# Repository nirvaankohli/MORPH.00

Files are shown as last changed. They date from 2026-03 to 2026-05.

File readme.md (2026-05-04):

# MORPH.00

---

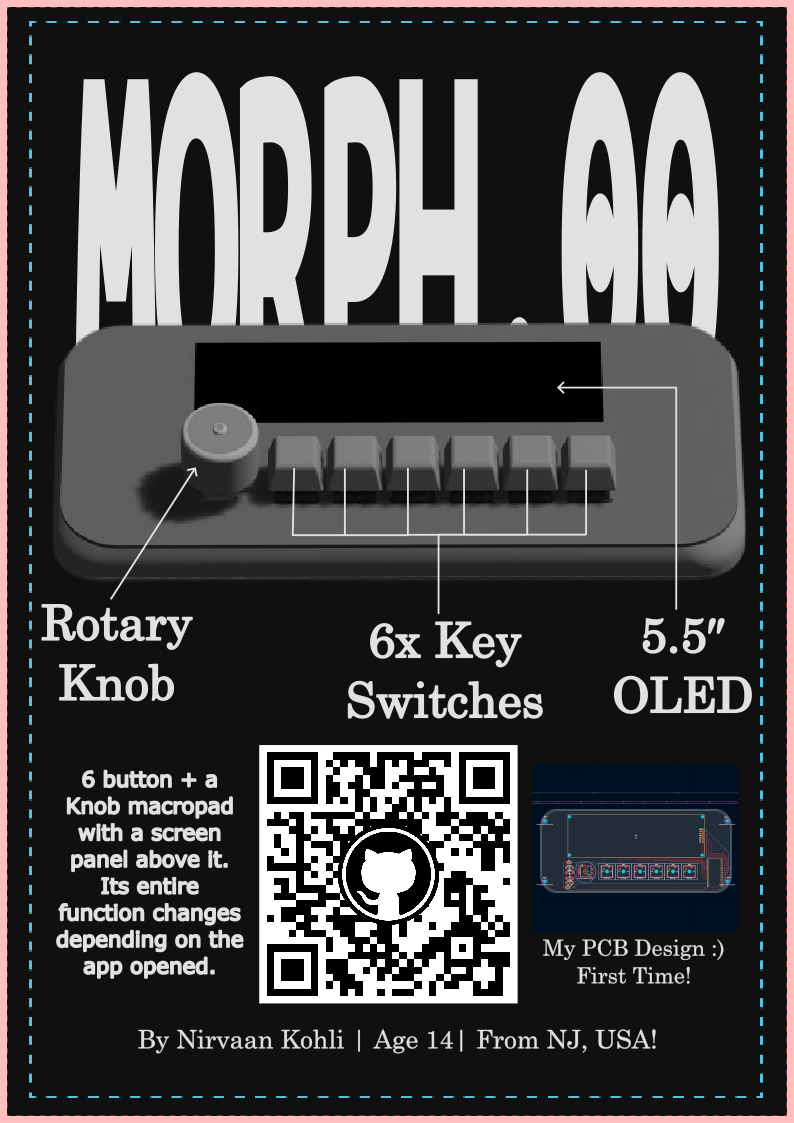
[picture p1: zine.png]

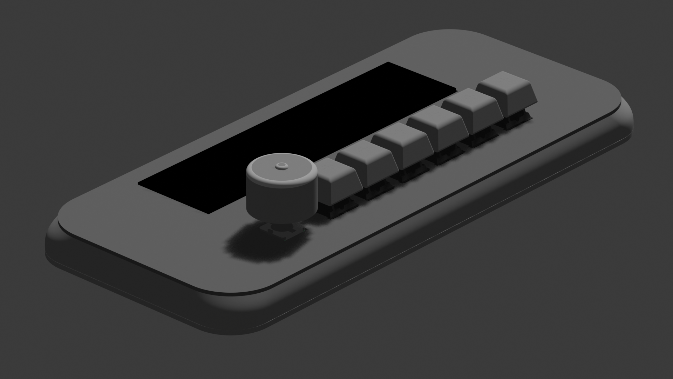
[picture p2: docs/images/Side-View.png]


MORPH.00 is a keyboard with 6 key switches and a rotary encoder that can change(morph their function). It also has an OLED to display each key or encoder's function at any given time. It is powered by the RP2040!

---

## Why choose this project?

When I initially found about fallout, I knew it was an one in a lifetime opportunity. I also knew that I did not know anything about hardware. So I looked online and on youtube and decided that a macropad was perfect for me. After a few days of brainstorming, I decided to settle for the best balance between challenging and easy(this project). Also it was pretty cool, cus like who would not want a keyboard that can change functions based on the app you are on to make work less repetitive. The use for this is legitimate because I can think of so many times in a day I press the same 6 button when in app. This would be really useful for myself, and that's why I chose to build it. Also a keyboard with a screen is rlly cool.

---

Looking back, this project was filled with a lot of firsts. I also had so much fun. Like who knew how relaxing some parts could be and how enraging others could be. Anyways, I learned my first real CAD software, onshape. I will definitely be using it in VEX Robotics as most of our team's CAD team seniored out. It took me some time to get comfortable but it is pretty cool. It was also my first time with KiCad. Making the schematic was interesting, pcb routing was so relaxing, but the errors sadly was not.

--- 

## A Little Summary

The keyboard is powered by a RP2040 on a [KB2040 Microcontroller](https://www.adafruit.com/product/5302?srsltid=AfmBOoqLa_n90N7_AYh5a78pJlOBana2qBx5fNuULukl6r5Ai2WtEuWO) running CircuitPython with many adafruit libraries. This is stuffed on the bottom-right side of the pcb board/keyboard and is the reason for it's goofy shape and proportions.

The six switches are Cherry MXs, the rotary encoder an EC11 Rotary Encoder, and the OLED a 5.5 Inch 256x64 display. There is also a part of this project on the host computer that sends info like key, encoder, or OLED changes to the keyboard.

--- 

# CAD Renderings

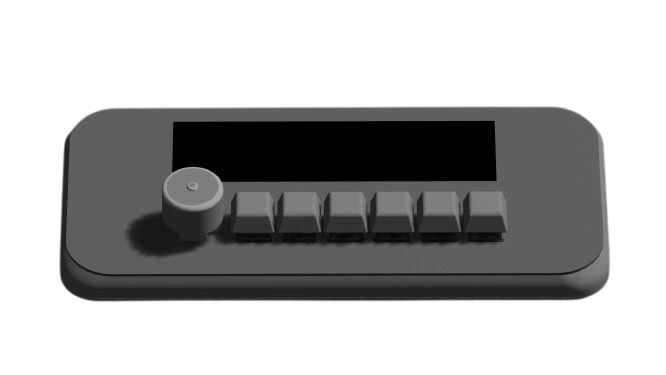
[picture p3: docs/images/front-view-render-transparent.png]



CAD was a very infuriating experience if I may add.

---

## PCB + Schematic

This is my final schematic

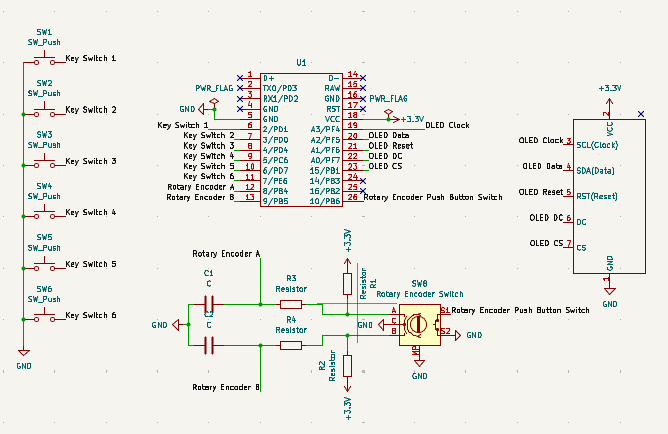
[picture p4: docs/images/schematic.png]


This schematic went through multiple, multiple changes. Like when I had to add power symbols, make a denouncer circuit, custom design the OLED symbol like 2 times, and change the GPIO pins for my OLED. I liked this portion a lot actually.

### Final PCB

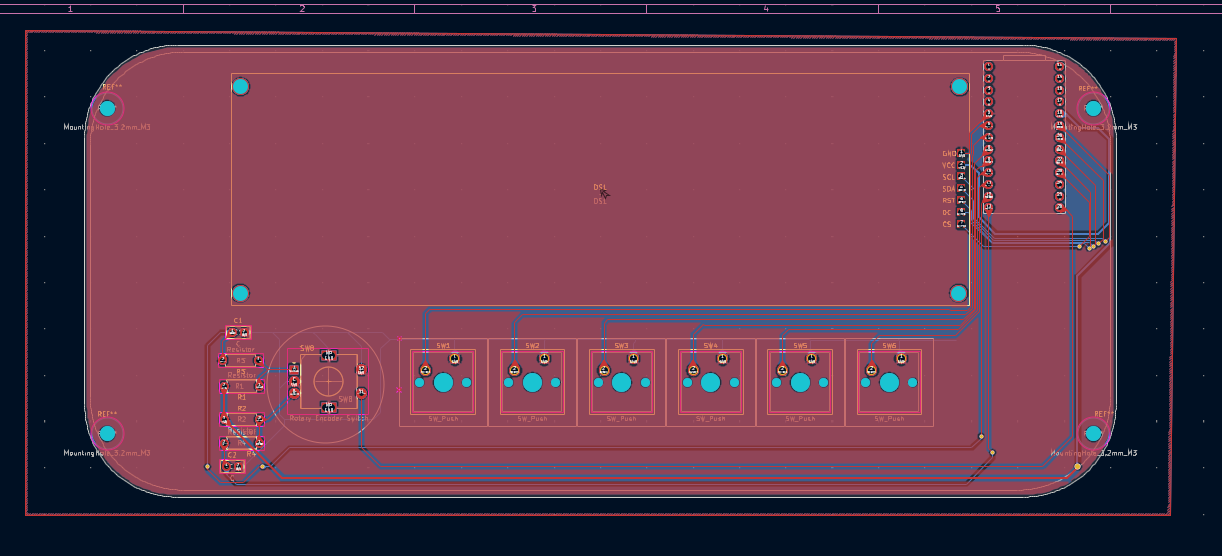
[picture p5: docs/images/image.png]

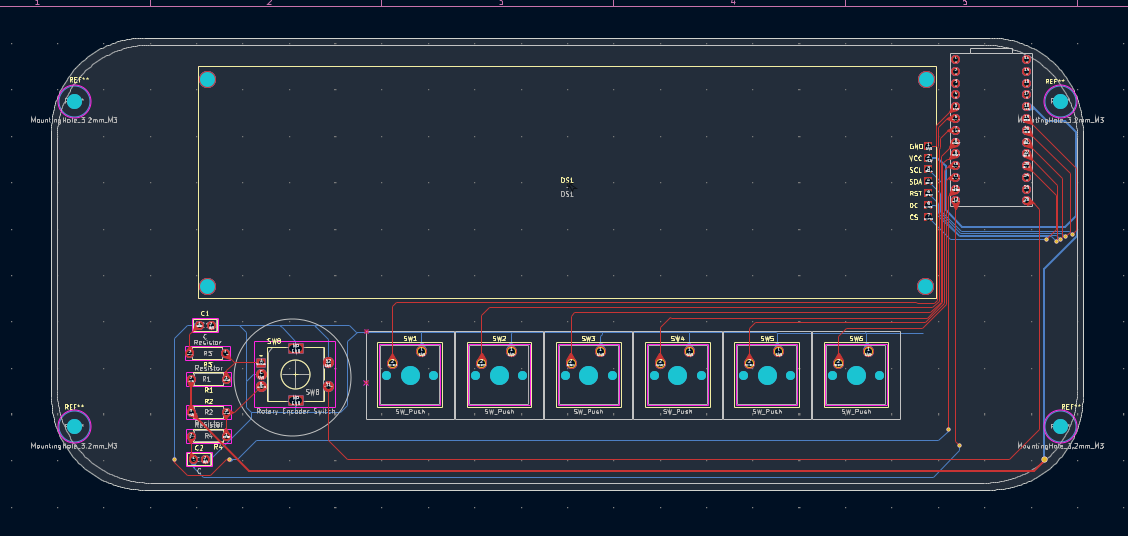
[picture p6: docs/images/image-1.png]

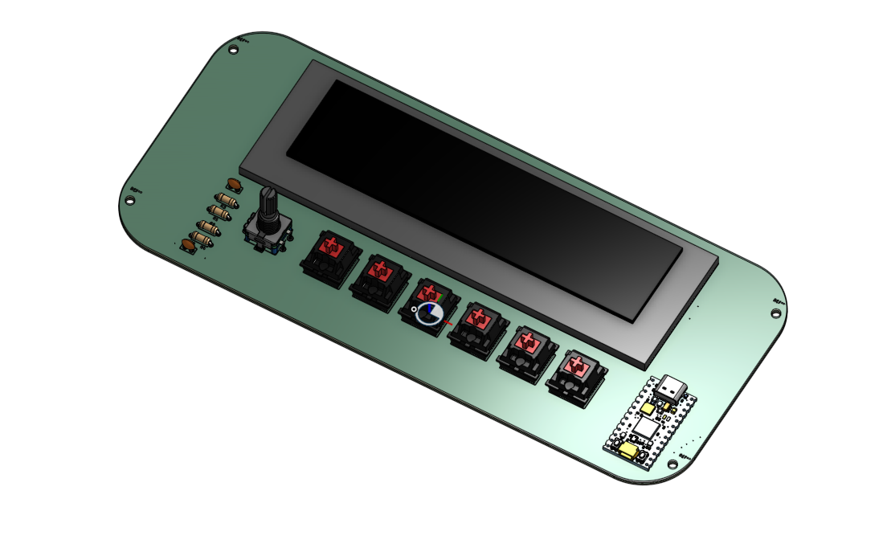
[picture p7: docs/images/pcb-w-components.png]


I added a lot of stuff bc the Internet said so :). So hopefully that was not a mistake. I was also just informed no 90 or acute angles so maybe not so final pcb :(.

----

### How to Use It?

This is relatively easy to use assuming it is all put together and well. All you need to do is drag firmware/software files into the KB2040 and let the host computer code run as a background process.

The computer process will be listening on a port. From there you can read the documentation available in code/keyboard/ on how to automate the OLED, switches, and encoder functions. 

From there, it is just using the macropad as a macropad.

---

# How to construct it?

Since I have not had the pleasure of constructing this, I can't tell you for sure but below is how to build it if everything goes as planned.

1. Soldering Components
   1. This step assumes you have bought everything in the BOM.
   2. The first step is to solder all the components on to the PCB.
      1. Use the various KiCad files as reference to know where to put components if you are confused.
2. 3D Printing Case
   1. This again assumes you have a 3D printer or some way to get your hands on a physical version of the case(files in /cad).
   2. This is pretty self-explanatory as you need to obtain all 3D printed objects in cad/print.
3. Assembling the Body of the Macropad
   1. Use M3 screws and nylocks to fasten the OLED on to the PCB plate.
   2. Put the top plate on the board.
   3. It should click into place thanks to the Cherry MX switches.
   4. Slide your usb c cable through the hole on the side of the case. For future use plug that cable into your host computer.
   5. Then take your 3mm Spacer and insert it between the bottom of the PCB and plate
   6. Insert the screw on the bottom of the bottom plate 
   7. On the top of the pcb plate place a M3 nylock and fasten.
   8. Repeat for all other 3 corners.
   9. For extra precaution optionally add some type of adhesive between the top plate's side and the bottom plate's edges.
4. Add Keycaps and Cover for Encoder
   1. Start by putting a keycap on one of the switches. The keycap should slide in and click.
   2. Repeat for the remaining 5 keycaps.
   3. For the Rotary Encoder, simply press down the rotary encoder cover on the Rotary Encoder, and with some force it should slide in.

---

Congrats! You have know constructed MORPH.00. Hopefully it should work.

---

# BOM

Check `bom.csv`!

---

# Onshape Link

[Onshape](https://cad.onshape.com/documents/fb2e845d06a2abfe6a4c7c6e/w/d1b8caaf10144fcbff733afe/e/741c88277487ad0443e0a772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)

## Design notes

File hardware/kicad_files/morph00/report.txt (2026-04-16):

Update symbol #FLG01 from 'power:PWR_FLAG' to 'power:PWR_FLAG': OK
Update symbol #PWR07 from 'power:+3.3V' to 'power:+3.3V': OK
Update symbol #FLG02 from 'power:PWR_FLAG' to 'power:PWR_FLAG': OK
Update symbol #PWR011 from 'power:GND' to 'power:GND': OK
Update symbol #PWR05 from 'power:+3.3V' to 'power:+3.3V': OK
Update symbol #PWR013 from 'power:GND' to 'power:GND': OK
Update symbol #PWR06 from 'power:+3.3V' to 'power:+3.3V': OK
Update symbol SW5 from 'Switch:SW_Push' to 'Switch:SW_Push': OK
Update symbol SW1 from 'Switch:SW_Push' to 'Switch:SW_Push': OK
Update symbol SW4 from 'Switch:SW_Push' to 'Switch:SW_Push': OK
Update symbol R3 from 'ScottoKeebs:Placeholder_Resistor' to 'ScottoKeebs:Placeholder_Resistor': OK
Update symbol R4 from 'ScottoKeebs:Placeholder_Resistor' to 'ScottoKeebs:Placeholder_Resistor': OK
Update symbol SW3 from 'Switch:SW_Push' to 'Switch:SW_Push': OK
Update symbol #PWR09 from 'power:GND' to 'power:GND': OK
Update symbol #PWR08 from 'power:GND' to 'power:GND': OK
Update symbol #PWR010 from 'power:+3.3V' to 'power:+3.3V': OK
Update symbol #PWR01 from 'power:GND' to 'power:GND': OK
Update symbol C1 from 'Device:C' to 'Device:C': OK
Update symbol C2 from 'Device:C' to 'Device:C': OK
Update symbol DS1 from 'OLED:TZT_5.5_OLED_SSD1322' to 'OLED:TZT_5.5_OLED_SSD1322': OK
Update symbol #PWR04 from 'power:GND' to 'power:GND': OK
Update symbol SW7 from 'Device:RotaryEncoder_Switch' to 'Device:RotaryEncoder_Switch': OK
Update symbol U1 from 'ScottoKeebs:MCU_Adafruit_KB2040' to 'ScottoKeebs:MCU_Adafruit_KB2040': OK
Update symbol #PWR02 from 'power:GND' to 'power:GND': OK
Update symbol SW6 from 'Switch:SW_Push' to 'Switch:SW_Push': OK
Update symbol #PWR03 from 'power:GND' to 'power:GND': OK
Update symbol SW2 from 'Switch:SW_Push' to 'Switch:SW_Push': OK
Update symbol R1 from 'ScottoKeebs:Placeholder_Resistor' to 'ScottoKeebs:Placeholder_Resistor': OK
Update symbol R2 from 'ScottoKeebs:Placeholder_Resistor' to 'ScottoKeebs:Placeholder_Resistor': OK
Update symbol #PWR012 from 'power:GND' to 'power:GND': OK

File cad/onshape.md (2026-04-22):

[Onshape Link](https://cad.onshape.com/documents/fb2e845d06a2abfe6a4c7c6e/w/d1b8caaf10144fcbff733afe/e/741c88277487ad0443e0a772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)

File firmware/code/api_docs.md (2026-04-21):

# API Docs

## Setup

To start, make sure you have the latest version of pip & python.

Then go into in an editor and edit `app.py`'s `OS` to your OS(windows, linux, or mac).

Depending on your os change either `LINUX_AND_MAC_PORT`(linux or mac) or `COM_NUM`(windows) to what port your macropad is connected to.

Once you have made sure of that run the following commands:

```bash

cd morph.00/code/computer
pip install -r requirements.txt
python app.py

```

The app should be up and running. You should get text in your terminal like(will change a little bit depending on your device):

```
 * Serving Flask app 'app'
 * Debug mode: on
WARNING: This is a development server. Do not use it in a production deployment. Use a production WSGI server instead.
 * Running on http://127.0.0.1:5000
Press CTRL+C to quit
 * Restarting with watchdog (windowsapi)
 * Debugger is active!
 * Debugger PIN: 116-642-025

```

To ensure the app is working get the first endpoint:

```text
GET /
```

or just run this:

`curl http://127.0.0.1:5000/`

If all is well you should get something like:

`{"message": "MORPH serial bridge is running."}`

## Keys

Below are the endpoints to change key functions.

```text
POST /messages/send
POST /messages/send/<key_num>
POST /messages/send/<key_num>/<executable_type>
```

* `POST /messages/send`
  * The payload needs to contain:
    * `type: "key_func_change"` - needs to be set to this if you want to change a key_function - can also be not be there and the app will handle the rest
    * `key_num` - The key number you want to change. Goes from 0 to 5 - order is left to right as the key number increases.
    * `executable_type` - what you want the key's function be
      * `string` - types a string
      * `key` - presses key
      * `key_combo` - presses key_combo
      * `consumer_control` - look at `adafruit_hid.consumer_control` dpcs for more info
    *  `executable`
       *   The executable itself - refer to each type's code to figure out what this should be
   * Other optional functions are available
* `POST /messages/send/<key_num>`
  * Same thing as `POST /messages/send` but `key_num` is specified in request url instead of in the payload
* `POST /messages/send/<key_num>/<executable_type>`
  * Same thing as `POST /messages/send` but `key_num` and `executable_type` is specified in request url instead of in the payload

## Rotary Encoder

```text
POST /encoder/send
POST /encoder/send/<encoder_action>
```

* `POST /encoder/send` 
  * The payload needs to contain:
    * `type: encoder_func_change`- needs to be set to this if you want to change a encoder_function - can also be not be there and the app will handle the rest
    * `encoder_action` 
      * `clockwise`- if clockwise movement affects the value
      * `counterclockwise` - if counterclockwise movement affects the value
      * `button` - use it as a button
    * `executable_type`
      * `string` - types a string
      * `key` - presses key
      * `key_combo` - presses key_combo
      * `consumer_control` - look at `adafruit_hid.consumer_control` dpcs for more info
    * `executable`
      * The executable itself - refer to each type's code to figure out what this should
* `POST /encoder/send/<encoder_action>` 
  * Same thing as `POST /encoder/send` but the `encoder_action` is specified in the request url
## OLED

```text
POST /oled/send
POST /oled/send/default
```

* `POST /oled/send` 
  * The payload needs to contain:
    * `type: display_change`- needs to be set to this if you want to change the display - can also be not be there and the app will handle the rest
    * `pixels` - the pixels you want to set the OLED to
* `POST /oled/send/default`
  * Same thing idk why I created a whole new endpoint

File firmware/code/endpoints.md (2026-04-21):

# API Endpoints

## General

```text
GET /
```

## Keys

```text
POST /messages/send
POST /messages/send/<key_num>
POST /messages/send/<key_num>/<executable_type>
```

## Rotary Encoder

```text
POST /encoder/send
POST /encoder/send/<encoder_action>
```

## OLED

```text
POST /oled/send
POST /oled/send/default
```

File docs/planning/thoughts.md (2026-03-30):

## Components to Use

- Microcontroller
  - Criterion
    - Have enough power to receive data from computer, process it and then display images on OLED
    - Be easy enough to use and be small enough for my form factor
  - Options
    - Raspberry Pi RP2040
      - Pros
        - Faster
        - More Memory
        - Used by most people
      - Cons
        - Still simple, just less than the ATmega32U4
    - ATmega32U4 (Arduino Pro Micro)
      - Pros
        - Simple
      - Cons
        - Performance
- Switches
  - Criterion
    - Durability
    - Consistency
    - Feel
  - Cherry MX Red
    - Both RED & BLack are equal and very good in durability and consistency
    - Light
    - Quiet
    - Smooth
  - Cherry MX Black
    - Both RED & BLack are equal and very good in durability and consistency
    - Smooth 
    - Heavy
    - When lubricated - buttery(big priority)

- Rotary Encoder
  - Criterion
    - Durable
    - Smooth
    - Consistent
  - Some I found online
    - Everything pointed to EC-11 type encoders - a bit about them
      - They are budget-friendly
      - 360 degree endless rotations
      - Compact Size

What I chose

- RP2040 - KB2040
- Cherry MX Black
- EC11 Rotary Encoder
- OLED: https://www.aliexpress.us/item/3256808352565291.html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 - 5.5 INCH 256 x 64

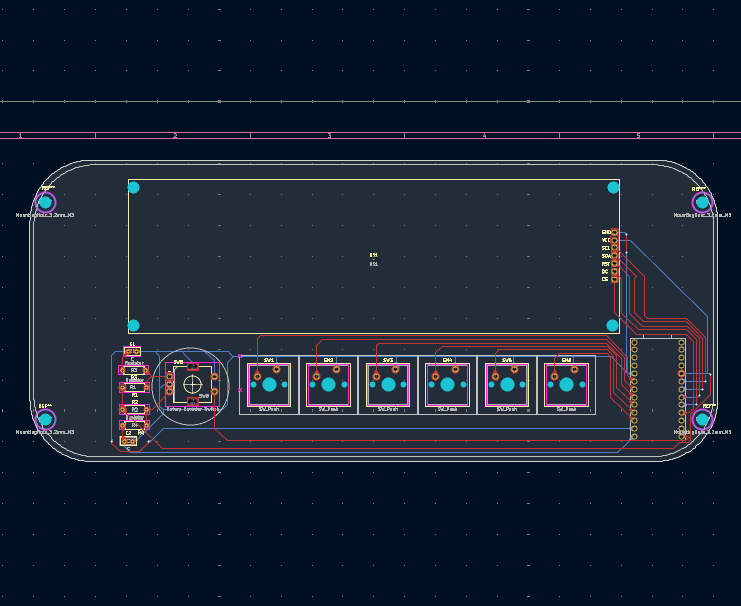
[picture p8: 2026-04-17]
hardware/kicad_files/morph00/Screenshot 2026-04-16 180610.png

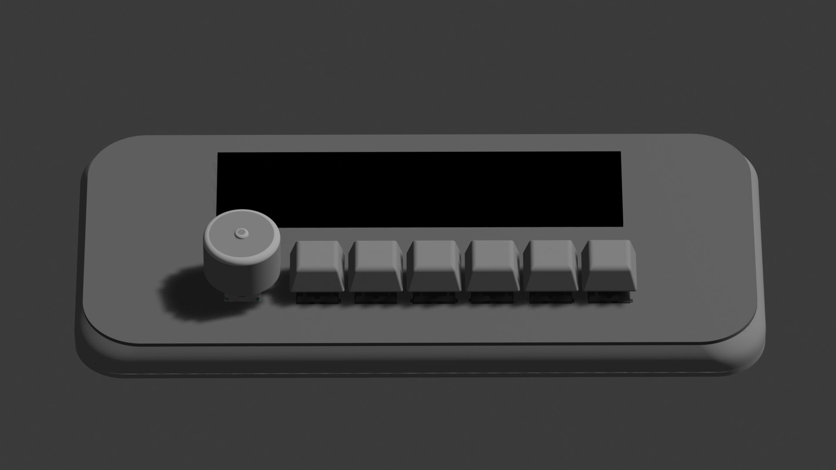
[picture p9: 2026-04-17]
hardware/kicad_files/morph00/Morph0.png

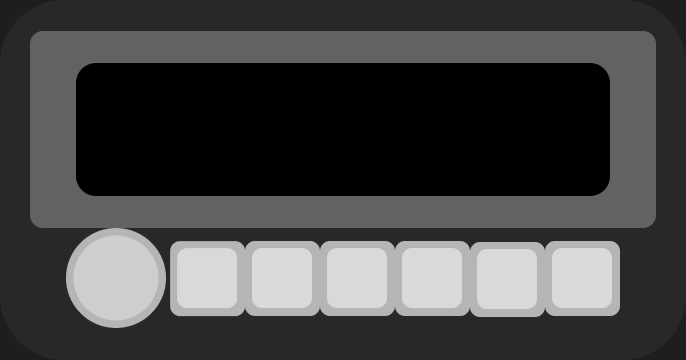
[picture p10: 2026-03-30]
docs/planning/figma/MORPH00.png

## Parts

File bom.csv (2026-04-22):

Part Name | Description | Quantity | Unit | Price Used | Total Price | Link
KB2040 | Microcontroller | 1 | piece | $8.95 | $8.95 | https://www.digikey.com/en/products/detail/adafruit-industries-llc/5302/15794634
5.5 Inch OLED LCD Display Green / Yellow Color TZT 256x64 Drive SSD1322 Interface SPI/ 8-bit Parallel Port For Arduino UNO R3 | OLED Display | 1 | piece | $35.83 | $35.83 | https://www.aliexpress.us/item/3256808352565291.html?curPageLogUid=hwy6wPt4U5Ww
360 Degree Rotary Encoder EC11 With Push Button 5Pin 20 Positions 20 Pulse Code Switch Handle 15/20MM Digital Potentiometer | G 20mm Plum handle Rotary Encoder | 1 | piece | $0.99 | $0.99 | https://www.aliexpress.us/item/3256807457768762.html?src=google&gatewayAdapt=glo2usa
Cherry MX HP 5 Pins Black Switch Hyperglide 60g Linear Custom Hot Swap MX Switches Mechanical Keyboard Gaming Switch Lubricatde | Cherry MX Black | 1 | 10 piece | $7.75 | $7.75 | https://www.aliexpress.us/item/3256808625020299.html?curPageLogUid=G7crrMlf338z
100pcs 50V monolithic ceramic capacitor 10PF ~ 10UF 22PF 47NF 220NF 1NF 4.7UF 1UF 100NF 330NF 0.1UF 102 104 105 106 103 473 334 | Capacitor(100 NF) | 4 | pieces | $2.04 | $2.04 | https://www.aliexpress.us/item/2251832786944590.html
100PCS/LOT 1/4W 1% Metal Film Resistor 0.25W 0.1 0.15 1.5 12 33 47 68 100 150 240 560 1K 3.3K 8.2K 10K 100K 680K 1M 10M 22M ohms | Resistors 10kΩ | 2 | pieces | $0.0099 | $0.99 | https://www.aliexpress.us/item/3256801441680644.html
USB C Cable | USB C Cable | 1 | pieces | $5.99 | $5.99 | https://a.co/d/0d05Bpac
M3 x 12mm Screws | M3 x 12mm Screws | 4 | pieces | $0.48 | $5.99 | https://a.co/d/0d2OkMbH
M3 4mm Spacers(Nylon) |  | 4 | pieces | $0.22 | $5.41 | https://a.co/d/0bYEqd7h
Filament | Just Filament | 107.35 | grams | $1.50 | $13.99 | https://a.co/d/03jPNyWm
Super Glue | Optional | Depends | Depends | $2.12 | $2.12 | https://a.co/d/06pQ8V2r

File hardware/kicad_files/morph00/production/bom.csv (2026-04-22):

Designator | Footprint | Quantity | Value | LCSC Part #
C1, C2 | C_Disc_D5.0mm_W2.5mm_P2.50mm | 2 | C
DS1 | TZT_5.5_OLED_SSD1322 | 1 | ~
R1, R2, R3, R4 | R_Axial_DIN0207_L6.3mm_D2.5mm_P7.62mm_Horizontal | 4 | Resistor
SW1, SW2, SW3, SW4, SW5, SW6 | SW_Cherry_MX_1.00u_PCB | 6 | SW_Push
SW8 | RotaryEncoder_Alps_EC11E-Switch_Vertical_H20mm | 1 | Rotary Encoder Switch
U1 | Adafruit_KB2040 | 1 | ~

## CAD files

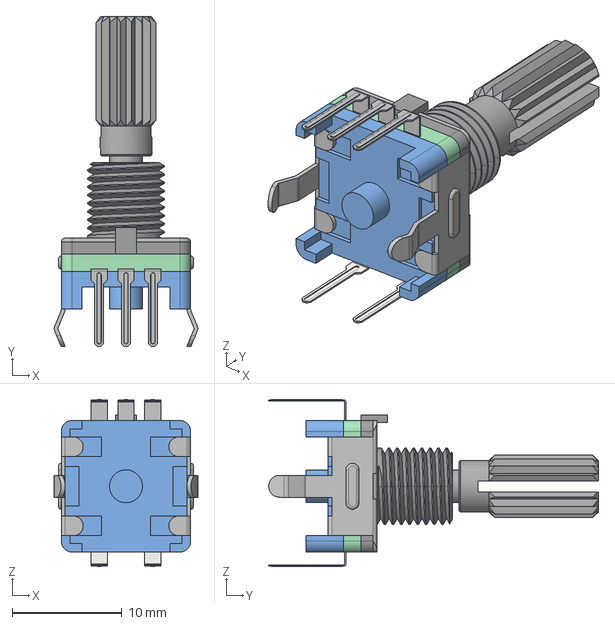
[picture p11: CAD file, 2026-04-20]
cad/components/EC11 Alps Rotary Encoder.step
13.1 x 30.1 x 15.3 mm

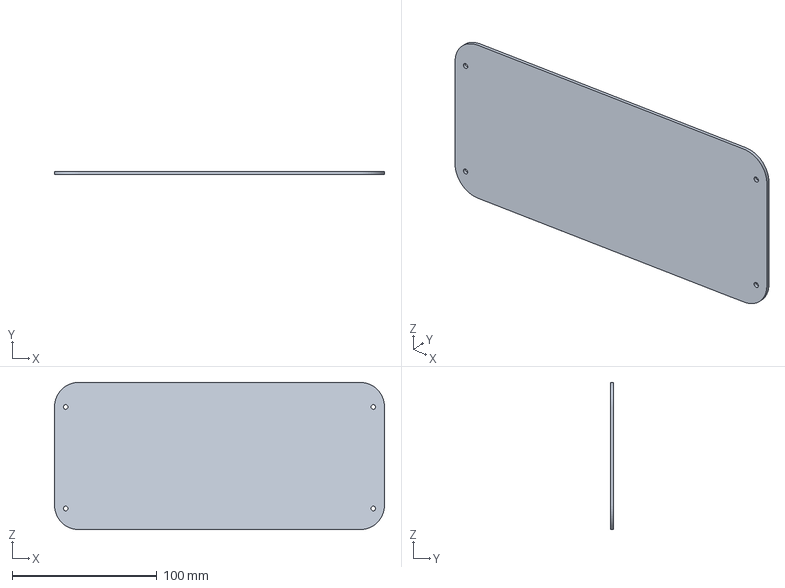
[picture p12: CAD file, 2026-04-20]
cad/print/Bottom Plate/Bottom Plate.step
228.3 x 2.00 x 101.9 mm

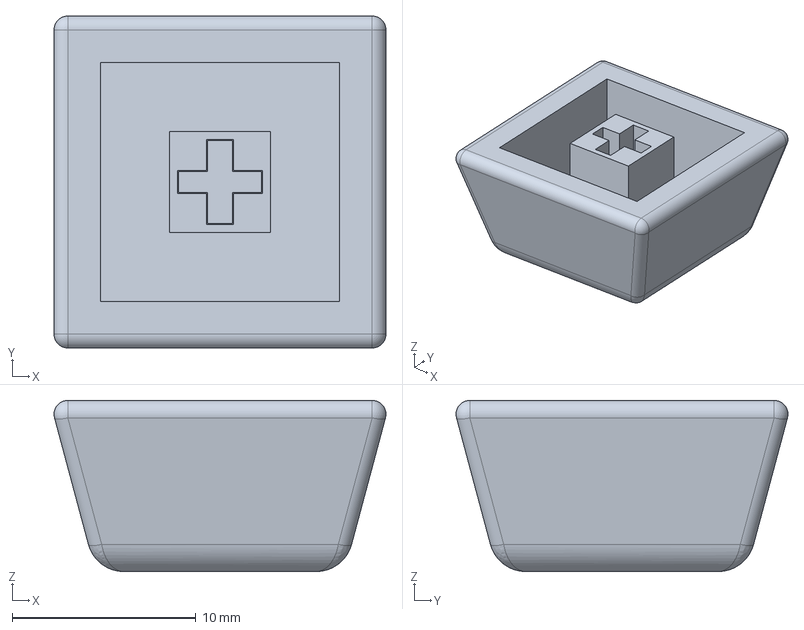
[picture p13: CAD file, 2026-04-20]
cad/print/Key Cap/Key Cap.step
18.0 x 18.0 x 9.30 mm

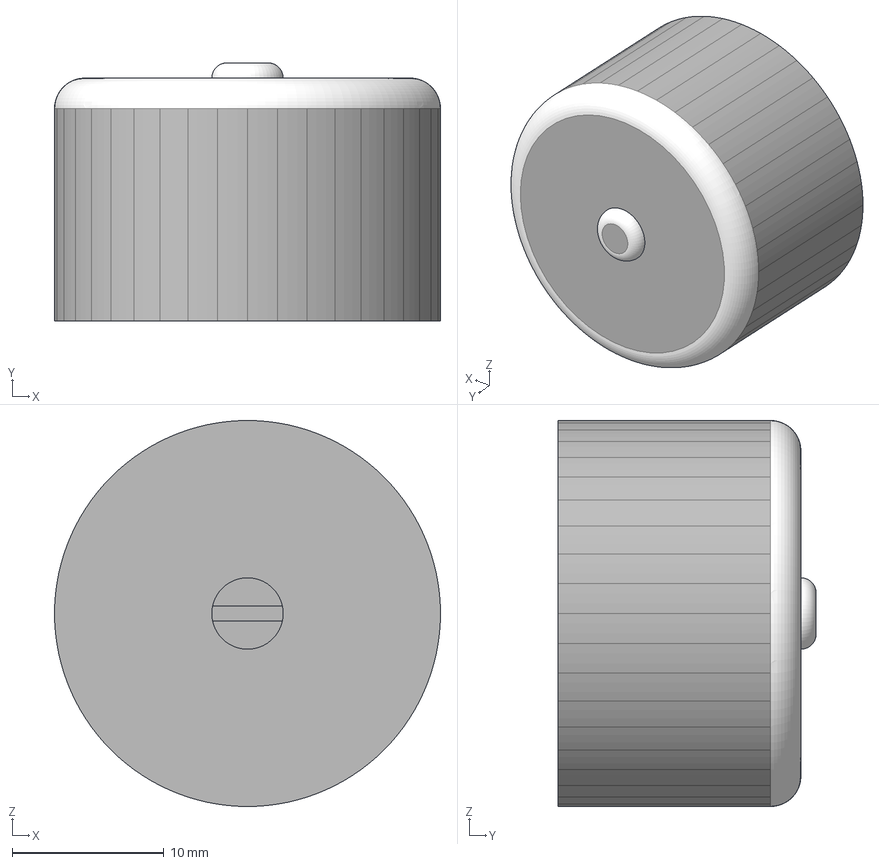
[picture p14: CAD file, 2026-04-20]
cad/print/Rotary Encoder Knob 3D Model/Rotary Encoder Knob 3D Model.step
25.4 x 17.0 x 25.4 mm

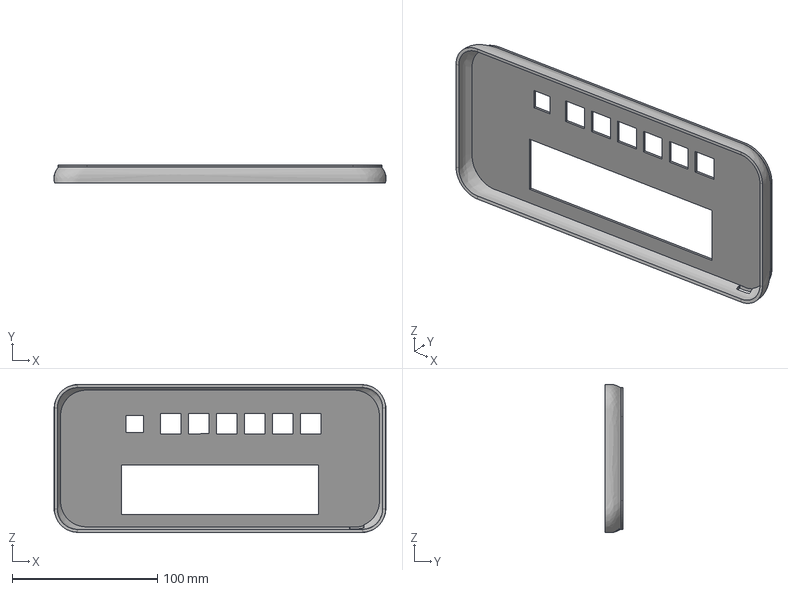
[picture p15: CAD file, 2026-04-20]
cad/print/Top Plate/Top Plate.step
228.3 x 12.5 x 101.9 mm

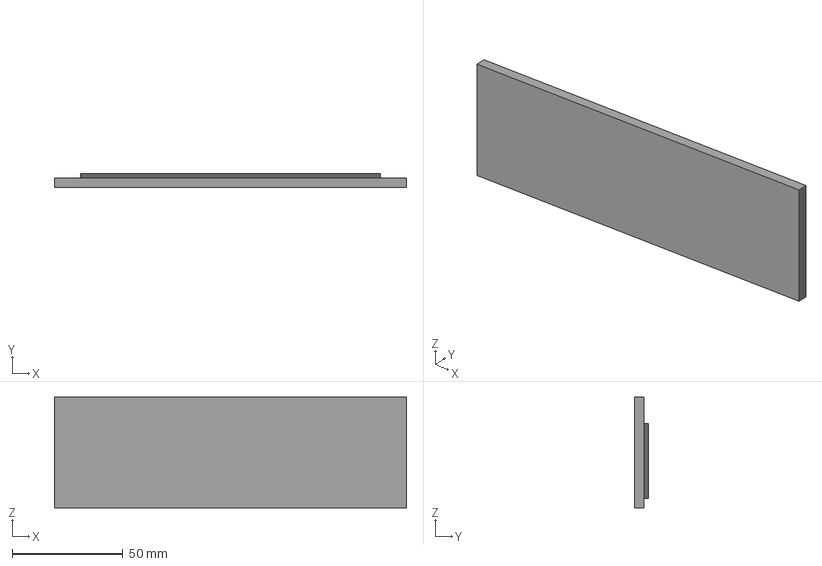
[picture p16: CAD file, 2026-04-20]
cad/components/OLED Screen Part Studio.step
159.0 x 6.40 x 50.0 mm

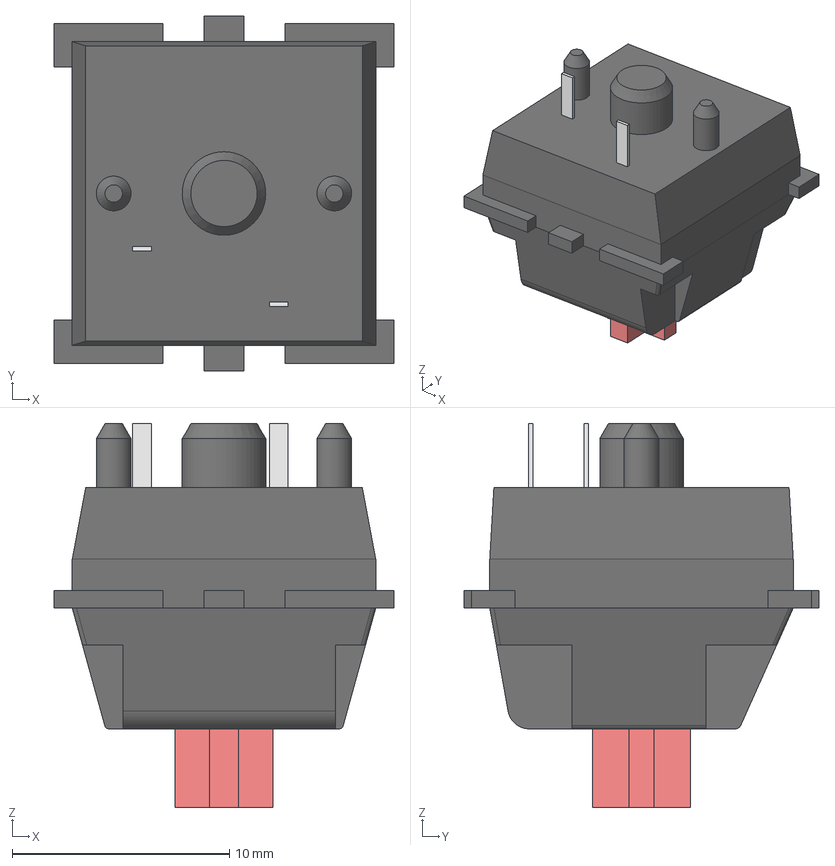
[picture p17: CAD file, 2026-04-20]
cad/components/Cherry MX Switch(Red).step
15.6 x 16.3 x 17.7 mm

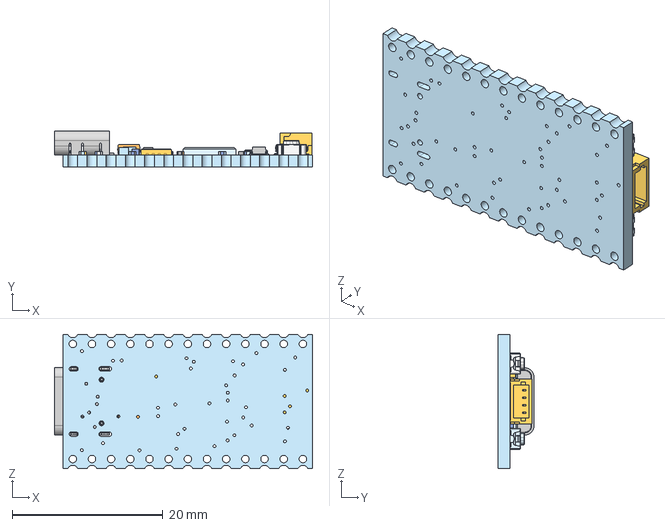
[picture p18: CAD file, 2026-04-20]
cad/components/Adafruit KB2040.step
34.2 x 4.77 x 17.8 mm
pcb 1.1.1 x 87

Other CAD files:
cad/print/Bottom Plate/Bottom Plate.obj
cad/print/Bottom Plate/Bottom Plate.stl
cad/print/Key Cap/Key Cap.obj
cad/print/Key Cap/Key Cap.stl
cad/print/Rotary Encoder Knob 3D Model/Rotary Encoder Knob 3D Model.obj
cad/print/Rotary Encoder Knob 3D Model/Rotary Encoder Knob 3D Model.stl
cad/print/Top Plate/Top Plate.obj
cad/print/Top Plate/Top Plate.stl

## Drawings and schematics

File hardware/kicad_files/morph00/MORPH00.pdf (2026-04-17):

# MORPH.00

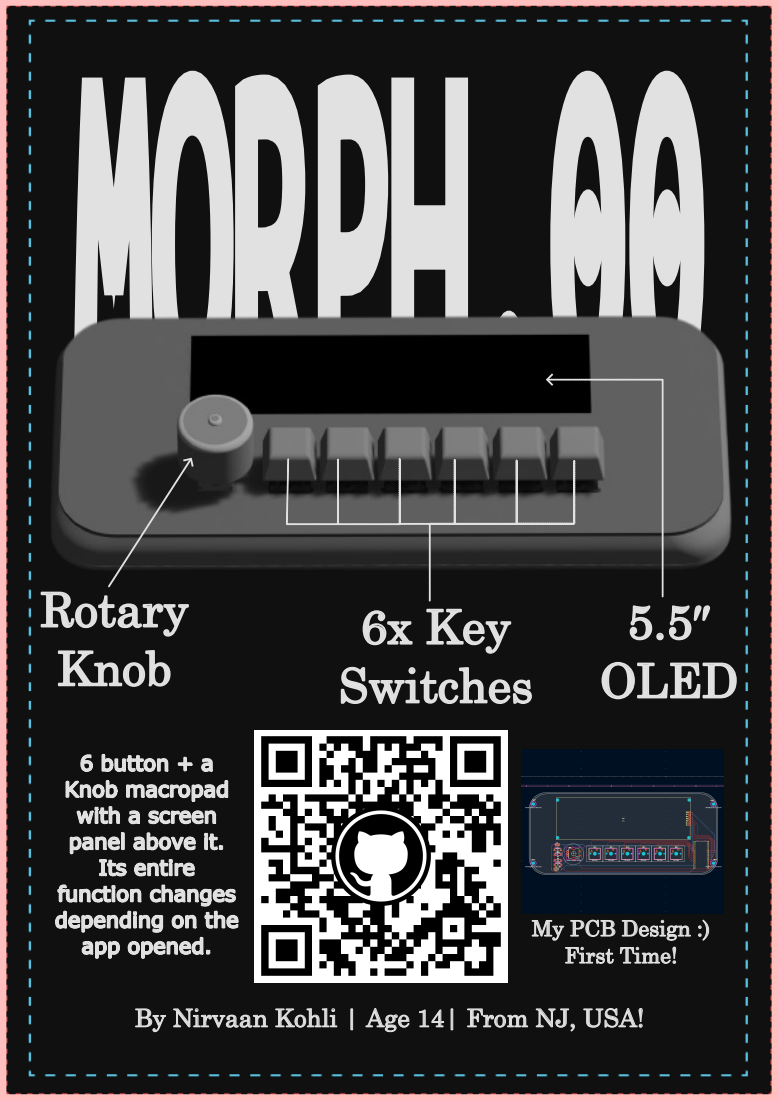
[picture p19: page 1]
Rotary Knob; 5.5″ OLED; 6x Key Switches; app opened.; My PCB Design :); First Time!

6 button + a
Knob macropad
with a screen
panel above it.
Its entire
function changes
depending on the

By Nirvaan Kohli | Age 14| From NJ, USA!

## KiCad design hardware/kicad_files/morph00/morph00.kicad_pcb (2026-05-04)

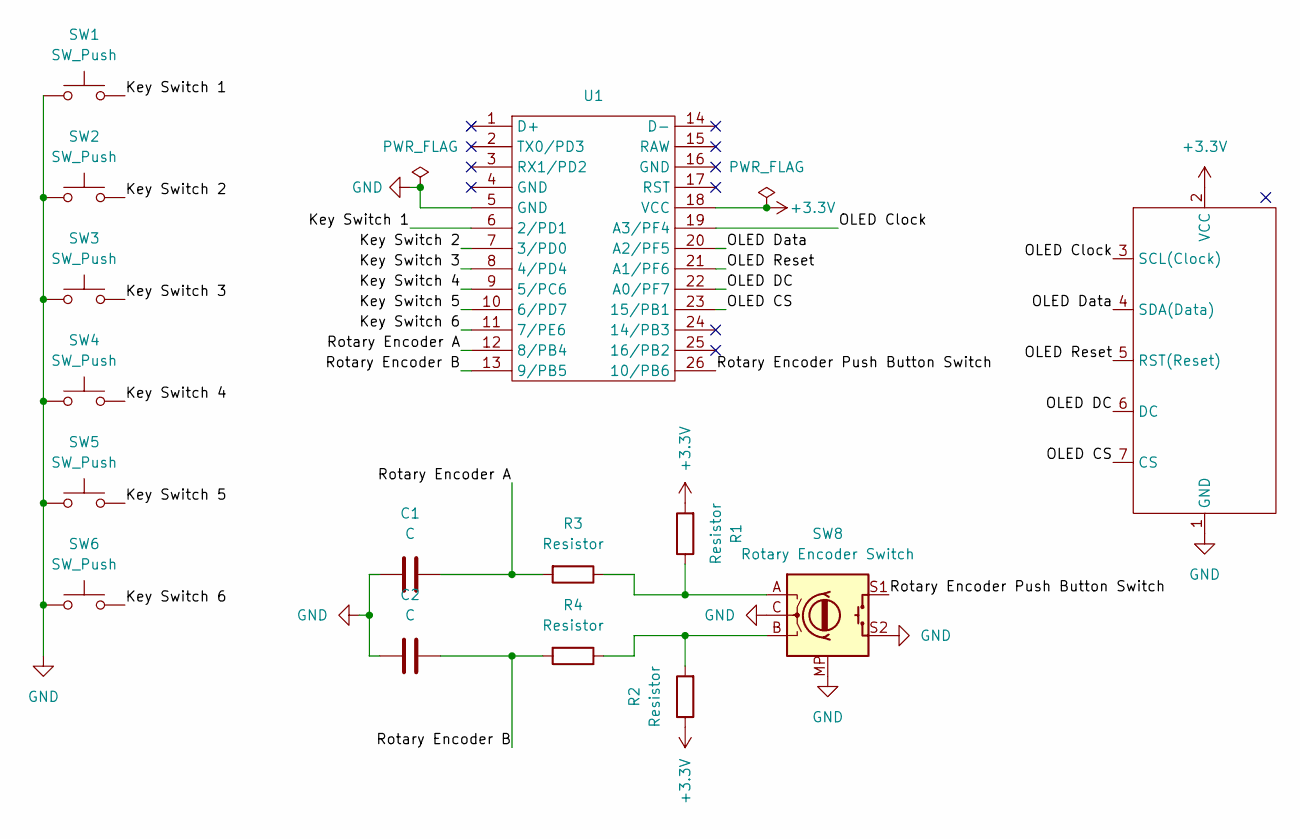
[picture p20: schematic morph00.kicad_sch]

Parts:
C1, C2: C; C_Disc_D5.0mm_W2.5mm_P2.50mm
DS1: TZT_5.5_OLED_SSD1322
R1, R2, R3, R4: Resistor; R_Axial_DIN0207_L6.3mm_D2.5mm_P7.62mm_Horizontal
SW1, SW2, SW3, SW4, SW5, SW6: SW_Push; SW_Cherry_MX_1.00u_PCB
SW8: Rotary Encoder Switch; RotaryEncoder_Alps_EC11E-Switch_Vertical_H20mm
U1: Adafruit_KB2040

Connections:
+3.3V: DS1.2 (VCC), R1.2, R2.1, U1.18 (VCC)
/Key Switch 1: SW1.2, U1.6 (2/PD1)
/Key Switch 2: SW2.2, U1.7 (3/PD0)
/Key Switch 3: SW3.2, U1.8 (4/PD4)
/Key Switch 4: SW4.2, U1.9 (5/PC6)
/Key Switch 5: SW5.2, U1.10 (6/PD7)
/Key Switch 6: SW6.2, U1.11 (7/PE6)
/OLED CS: DS1.7 (CS), U1.23 (15/PB1)
/OLED Clock: DS1.3 (SCL(Clock)), U1.19 (A3/PF4)
/OLED DC: DS1.6 (DC), U1.22 (A0/PF7)
/OLED Data: DS1.4 (SDA(Data)), U1.20 (A2/PF5)
/OLED Reset: DS1.5 (RST(Reset)), U1.21 (A1/PF6)
/Rotary Encoder A: C1.1, R3.2, U1.12 (8/PB4)
/Rotary Encoder B: C2.1, R4.2, U1.13 (9/PB5)
/Rotary Encoder Push Button Switch: SW8.S1, U1.26 (10/PB6)
GND: C1.2, C2.2, DS1.1 (GND), SW1.1, SW2.1, SW3.1, SW4.1, SW5.1, SW6.1, SW8.C, SW8.MP, SW8.S2, U1.5 (GND)
unnamed: R1.1, R3.1, SW8.A
unnamed: R2.2, R4.1, SW8.B

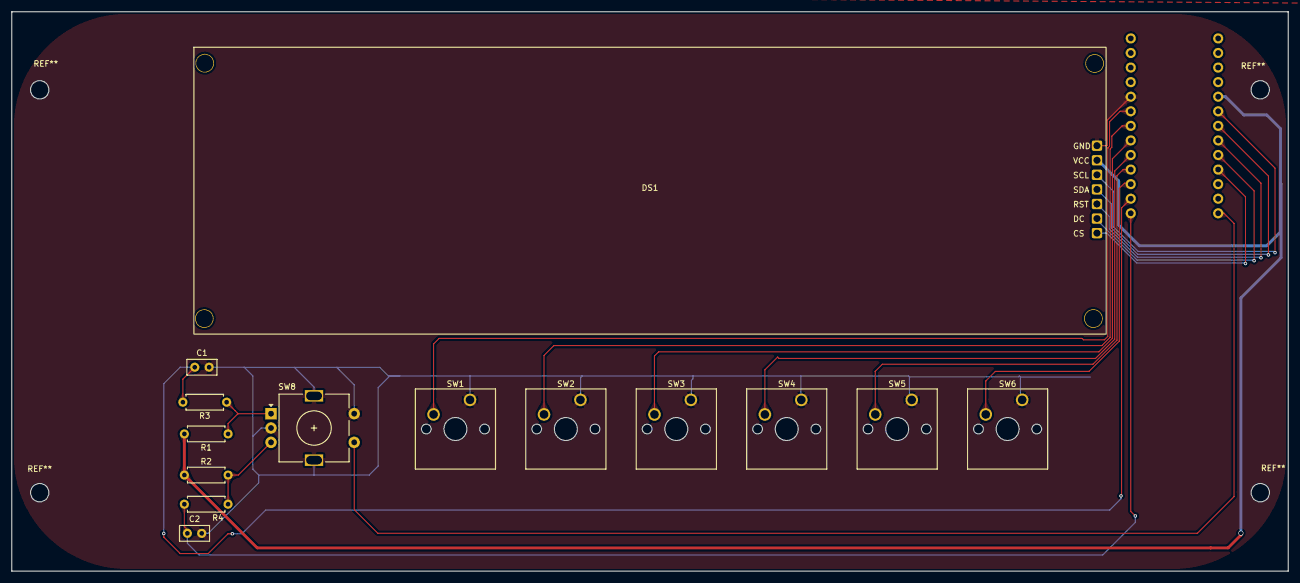
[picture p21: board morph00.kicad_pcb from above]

Board: 2 copper layers, 222.5 x 97.5 mm, 15 parts (0 on the bottom side), 18 nets.

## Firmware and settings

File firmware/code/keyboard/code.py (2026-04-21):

import usb_hid

from adafruit_hid.keyboard import Keyboard
from adafruit_hid.keycode import Keycode
from adafruit_hid.keyboard_layout_us import KeyboardLayoutUS

import keypad

import board
import busio
import digital_io
import rotaryio
import usb_cdc

import json
import binascii
import time

from adafruit_hid.consumer_control import ConsumerControl
from adafruit_hid.consumer_control_code import ConsumerControlCode

import displayio
import fourwire
from adafruit_ssd1322 import SSD1322



# Set Up/Configuration

oled_pins = {}
(
    oled_pins["sck"],
    oled_pins["mosi"],
    oled_pins["cs"],
    oled_pins["dc"],
    oled_pins["rst"],

) = (board.SCK, board.MOSI, board.A2, board.A0, board.A1)

spi = busio.SPI(oled_pins["sck"], oled_pins["mosi"])

cs = digital_io.DigitalInOut(oled_pins["cs"])
dc = digital_io.DigitalInOut(oled_pins["dc"])
rst = digital_io.DigitalInOut(oled_pins["rst"])

display_bus = fourwire.FourWire(
    spi, command=dc, chip_select=cs, reset=rst, baudrate=1000000
)

display = SSD1322(display_bus, width=256, height=64)

kbd = Keyboard(usb_hid.devices)  # set keyboard object
cc = ConsumerControl(usb_hid.devices)
serial = usb_cdc.data  # setting up the desktop and macropad communication
layout = KeyboardLayoutUS(kbd)

key_mapping = {
    0: [6, board.D2, None],
    1: [7, board.D3, None],
    2: [8, board.D4, None],
    3: [9, board.D5, None],
    4: [10, board.D6, None],
    5: [11, board.D8, None],
}  # mapping of key - key_num : [key_pin_num, board.pin, function]

encoder_pins = {
    "a": board.D7,
    "b": board.D9,
    "button": board.D10,
}

encoder_mapping = {
    "clockwise": None,
    "counterclockwise": None,
    "button": None,
}


# init keys - use dictionary

keys = keypad.Keys(
    tuple(key_mapping[i][1] for i in key_mapping), value_when_pressed=False, pull=True
)

encoder = rotaryio.IncrementalEncoder(encoder_pins["a"], encoder_pins["b"])
encoder_button = keypad.Keys((encoder_pins["button"],), value_when_pressed=False, pull=True)


class keyboard_action:

    def __init__(self, json_load):

        self.json_load = json_load

        self.executable_type = json_load["executable_type"]
        self.executable_type_options = ["string", "key", "key_combo", "consumer_control"]

        self.key_num = json_load.get("key_num")
        self.encoder_action = json_load.get("encoder_action")

        try:
            self.press = (
                True
                if json_load.get("kbd_press_or_send", json_load.get("press_or_send"))
                == "press"
                else False
            )
        except AttributeError:
            self.press = False

        if self.executable_type not in self.executable_type_options:

            raise ValueError(
                f"Invalid executable type: {self.executable_type}. Must be one of {self.executable_type_options}."
            )

        self.executable = self.get_executable_value()

        if self.executable_type == "consumer_control":

            self.executable_function = cc.send
            self.press_hold = []

        elif self.press:

            self.executable_function = kbd.press

            try:

                self.press_hold = json_load["kbd_press_hold"]

                if not isinstance(self.press_hold, list):

                    self.press_hold = [self.press_hold]

            except KeyError:

                self.press_hold = [1.0]

        else:

            self.executable_function = kbd.send
            self.press_hold = []

        if self.executable_type == "key_combo":

            try:

                if "key_combo_separate" in json_load:

                    self.key_combo_seperate = json_load["key_combo_separate"]

                else:

                    self.key_combo_seperate = json_load["key_combo_seperate"]

            except KeyError:

                self.key_combo_seperate = len(self.press_hold) > 1

    def get_executable_value(self):

        executable = self.json_load["executable"]

        if self.executable_type == "string":

            return executable

        if self.executable_type == "consumer_control":

            consumer_control_type = self.json_load["consumer_control_type"]

            if consumer_control_type == "int":

                return executable

            if consumer_control_type == "ConsumerControlCode":

                return (
                    getattr(ConsumerControlCode, executable)
                    if isinstance(executable, str)
                    else executable
                )

            raise ValueError(
                "Invalid consumer control type. Must be 'int' or 'ConsumerControlCode'."
            )

        key_stroke_type = self.json_load["key_stroke_type"]

        if key_stroke_type == "int":

            return executable

        if key_stroke_type == "Keycode":

            if self.executable_type == "key_combo":

                return [
                    getattr(Keycode, key) if isinstance(key, str) else key
                    for key in executable
                ]

            return (
                getattr(Keycode, executable)
                if isinstance(executable, str)
                else executable
            )

        raise ValueError(
            f"Invalid key stroke type: {key_stroke_type}. Must be 'int' or 'Keycode' for key presses."
        )

    def get_press_hold(self, index=0):

        if not self.press_hold:

            return 0

        if index < len(self.press_hold):

            return self.press_hold[index]

        return self.press_hold[0]

    def execute(self):

        # execute the action based on the type of action

        if self.executable_type == "string":

            layout.write(self.executable)

        elif self.executable_type == "key":

            if self.press:

                self.executable_function(self.executable)

                if self.press_hold:

                    time.sleep(self.get_press_hold())

                    kbd.release(self.executable)

            else:

                self.executable_function(self.executable)

        elif self.executable_type == "key_combo":

            if self.press:

                if self.key_combo_seperate:

                    for i, key in enumerate(self.executable):

                        self.executable_function(key)

                        if self.press_hold:

                            time.sleep(self.get_press_hold(i))

                            kbd.release(key)

                else:

                    self.executable_function(*self.executable)

                    if self.press_hold:

                        time.sleep(self.get_press_hold())

                        kbd.release(*self.executable)

            else:

                if self.key_combo_seperate:

                    for key in self.executable:

                        self.executable_function(key)

                else:

                    self.executable_function(*self.executable)

        elif self.executable_type == "consumer_control":

            self.executable_function(self.executable)

        return True


def array_to_display_io_bitmap(array, width, height):

    bitmap = displayio.Bitmap(width, height, 2)

    for y in range(height):

        for x in range(width):

            bitmap[x, y] = array[y * width + x]

    return bitmap


def bitmap_to_display_io_tilegrid(bitmap, width, height):

    palette = displayio.Palette(2)
    palette[0] = 0x000000  # Black
    palette[1] = 0xFFFFFF  # White

    tilegrid = displayio.TileGrid(bitmap, pixel_shader=palette)

    return tilegrid


def unpack_pixels(readable):

    if readable.get("encoding") != "1bpp_base64":

        return readable["pixels"]

    raw_pixels = binascii.a2b_base64(readable["pixels"].encode("ascii"))
    pixels = []

    for byte in raw_pixels:

        for shift in range(7, -1, -1):

            pixels.append((byte >> shift) & 1)

    return pixels[: display.width * display.height]


def decrypt_serial_display_change(readable):

    array_of_pixels = unpack_pixels(readable)

    if len(array_of_pixels) != display.width * display.height:

        raise ValueError("Pixel array length does not match display size.")

    bitmap = array_to_display_io_bitmap(
        array_of_pixels, display.width, display.height
    )

    tile_grid = bitmap_to_display_io_tilegrid(bitmap, display.width, display.height)

    return bitmap, tile_grid


def decrypt_serial_key_change(readable):

    return keyboard_action(readable)


def decrypt_serial_encoder_change(readable):

    return keyboard_action(readable)


def get_key_mapping_index(key_num):

    if key_num in key_mapping:

        return key_num

    for i in key_mapping:

        if key_mapping[i][0] == key_num:

            return i

    return None


def check_if_hold_key(current, old):

    return bool(
        old and current.key_number == old.key_number and current.pressed and old.pressed
    )


# loop

old_key_event = None
last_encoder_position = encoder.position
serial_buffer = b""

while True:

    key_event = keys.events.get()

    if key_event:

        key_number = key_event.key_number
        pressed = key_event.pressed
        hold = check_if_hold_key(key_event, old_key_event)

        try:

            key_func = key_mapping[key_number][2]

        except KeyError:

            key_func = None

        if (not hold) and pressed and key_func:

            success = key_func.execute()

        old_key_event = key_event

    encoder_position = encoder.position

    if encoder_position != last_encoder_position:

        if encoder_position > last_encoder_position:

            encoder_func = encoder_mapping["clockwise"]

        else:

            encoder_func = encoder_mapping["counterclockwise"]

        if encoder_func:

            success = encoder_func.execute()

        last_encoder_position = encoder_position

    encoder_button_event = encoder_button.events.get()

    if encoder_button_event and encoder_button_event.pressed:

        encoder_func = encoder_mapping["button"]

        if encoder_func:

            success = encoder_func.execute()

    if serial is not None and serial.in_waiting > 0:

        serial_buffer += serial.read(serial.in_waiting)

        while b"\n" in serial_buffer:

            data, serial_buffer = serial_buffer.split(b"\n", 1)

            if not data:

                continue

            serial.write(b"Received: " + data + b"\n")

            try:

                readable = json.loads(data.decode("utf-8"))

                if readable.get("type") == "key_func_change":

                    obj = decrypt_serial_key_change(readable)
                    mapping_index = get_key_mapping_index(obj.key_num)

                    if mapping_index is not None:

                        key_mapping[mapping_index][2] = obj

                elif readable.get("type") == "encoder_func_change":

                    obj = decrypt_serial_encoder_change(readable)

                    if obj.encoder_action in encoder_mapping:

                        encoder_mapping[obj.encoder_action] = obj

                elif readable.get("type") == "display_change":

                    bitmap, tile_grid = decrypt_serial_display_change(readable)
                    display.show(tile_grid)

                else:

                    print("Invalid data received:", data)

            except Exception as error:

                print("Invalid data received:", data, error)

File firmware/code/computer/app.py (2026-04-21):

import base64
import json

from flask import Flask, jsonify, request
import serial

OS = "windows"  # Change to "linux" or "mac" as needed
COM_NUM = 6  # leave this as None if not on windows
LINUX_AND_MAC_PORT = "/dev/ttyUSB0"  # Change as needed for Linux/Mac
BAUD_RATE = 9600
DISPLAY_WIDTH = 256
DISPLAY_HEIGHT = 64
DISPLAY_PIXELS = DISPLAY_WIDTH * DISPLAY_HEIGHT

serial_string = LINUX_AND_MAC_PORT if OS in ["linux", "mac"] else f"COM{COM_NUM}"

app = Flask(__name__)
ser = serial.Serial(serial_string, BAUD_RATE, timeout=1, write_timeout=1)


def double_check_payload(data, type_):

    if type_ in ["key_func_change", "encoder_func_change"]:

        key_func_change_required_fields = ["executable_type", "executable"]

        if type_ == "key_func_change":

            key_func_change_required_fields.append("key_num")

        else:

            key_func_change_required_fields.append("encoder_action")

        for field in key_func_change_required_fields:

            if field not in data:

                raise ValueError(
                    f"Missing required field '{field}' for function change."
                )

        if data["executable_type"] not in [
            "string",
            "key",
            "key_combo",
            "consumer_control",
        ]:

            raise ValueError("Invalid executable_type.")

        if (
            data["executable_type"] in ["key", "key_combo"]
            and "key_stroke_type" not in data
        ):

            raise ValueError("Missing required field 'key_stroke_type' for key action.")

        if (
            data["executable_type"] == "consumer_control"
            and "consumer_control_type" not in data
        ):

            raise ValueError(
                "Missing required field 'consumer_control_type' for consumer control action."
            )

        if type_ == "encoder_func_change" and data["encoder_action"] not in [
            "clockwise",
            "counterclockwise",
            "button",
        ]:

            raise ValueError("Invalid encoder_action.")

    elif type_ == "display_change":

        if "pixels" not in data:

            raise ValueError("Missing required field 'pixels' for display change.")

        if len(data["pixels"]) != DISPLAY_PIXELS:

            raise ValueError("Display change must include exactly 16384 pixels.")

    else:

        raise ValueError("Unknown message type.")

    return True


def pack_pixels(pixels):

    packed = bytearray(DISPLAY_PIXELS // 8)

    for i, pixel in enumerate(pixels):

        if pixel:

            packed[i // 8] |= 1 << (7 - (i % 8))

    return base64.b64encode(packed).decode("ascii")


def build_serial_payload(payload):

    double_check_payload(payload, payload.get("type", ""))
    serial_payload = dict(payload)

    if serial_payload["type"] == "display_change":

        serial_payload["encoding"] = "1bpp_base64"
        serial_payload["pixels"] = pack_pixels(serial_payload["pixels"])

    return serial_payload


def send_serial_payload(payload):

    serial_payload = build_serial_payload(payload)
    message = json.dumps(serial_payload, separators=(",", ":")).encode("utf-8") + b"\n"
    ser.write(message)
    ser.flush()

    return message


def require_json_body():
    data = request.get_json(silent=True)
    if not isinstance(data, dict):
        raise ValueError("Request body must be a JSON object.")
    return data


@app.errorhandler(ValueError)
def handle_value_error(error):
    return jsonify({"status": "error", "error": str(error)}), 400


@app.route("/")
def index():

    return jsonify({"message": "MORPH serial bridge is running."})


@app.route("/messages/send", methods=["POST"])
def send_data():
    data = require_json_body()
    data.setdefault("type", "key_func_change")

    if data["type"] != "key_func_change":
        raise ValueError("Keyboard messages must use type 'key_func_change'.")

    send_serial_payload(data)
    return jsonify({"status": "sent", "payload": data})


@app.route("/messages/send/<int:key_num>", methods=["POST"])
def send_message(key_num):
    data = require_json_body()
    data["key_num"] = key_num
    data.setdefault("type", "key_func_change")

    if data["type"] != "key_func_change":
        raise ValueError("Keyboard messages must use type 'key_func_change'.")

    send_serial_payload(data)
    return jsonify({"status": "sent", "payload": data})


@app.route("/messages/send/<int:key_num>/<executable_type>", methods=["POST"])
def send_message_type(key_num, executable_type):
    data = require_json_body()
    data["key_num"] = key_num
    data["executable_type"] = executable_type
    data.setdefault("type", "key_func_change")

    if data["type"] != "key_func_change":
        raise ValueError("Keyboard messages must use type 'key_func_change'.")

    send_serial_payload(data)
    return jsonify({"status": "sent", "payload": data})


@app.route("/encoder/send", methods=["POST"])
def send_encoder_data():
    data = require_json_body()
    data.setdefault("type", "encoder_func_change")

    if data["type"] != "encoder_func_change":
        raise ValueError("Encoder messages must use type 'encoder_func_change'.")

    send_serial_payload(data)
    return jsonify({"status": "sent", "payload": data})


@app.route("/encoder/send/<encoder_action>", methods=["POST"])
def send_encoder_message(encoder_action):
    data = require_json_body()
    data["encoder_action"] = encoder_action
    data.setdefault("type", "encoder_func_change")

    if data["type"] != "encoder_func_change":
        raise ValueError("Encoder messages must use type 'encoder_func_change'.")

    send_serial_payload(data)
    return jsonify({"status": "sent", "payload": data})


@app.route("/oled/send", methods=["POST"])
def send_oled():
    data = require_json_body()
    data.setdefault("type", "display_change")

    if data["type"] != "display_change":
        raise ValueError("OLED messages must use type 'display_change'.")
    if "pixels" not in data:
        raise ValueError("OLED messages must include 'pixels'.")

    send_serial_payload(data)
    return jsonify({"status": "sent", "payload": data})


@app.route("/oled/send/default", methods=["POST"])
def send_oled_default():
    data = require_json_body()
    data["type"] = "display_change"

    if "pixels" not in data:
        raise ValueError("OLED messages must include 'pixels'.")

    send_serial_payload(data)
    return jsonify({"status": "sent", "payload": data})


if __name__ == "__main__":
    app.run(debug=True)

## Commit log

2026-03-30 KICAD FILes
    [morph00.kicad_pcb, morph00.kicad_sch]
2026-03-31 Changed some stuff
    [morph00.kicad_sch]
2026-04-20 Added CAD files from Onshape including electrical components models, 3D print finals, and assemblies.
    [Adafruit KB2040.step, Bottom Plate.obj, Bottom Plate.step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]
2026-04-21 code and pcb changes and docs
    [morph00.kicad_pcb]
2026-04-22 I think im done
    [bom.csv, morph00.csv]
2026-04-22 Final Commit hopefully
    [Adafruit KB2040.step, Bottom Plate.obj, Bottom Plate.step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]
2026-05-04 Uodate for final submission
    [morph00.kicad_pcb]
